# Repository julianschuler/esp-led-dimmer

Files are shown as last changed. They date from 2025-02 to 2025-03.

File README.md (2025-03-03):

# ESP LED Dimmer

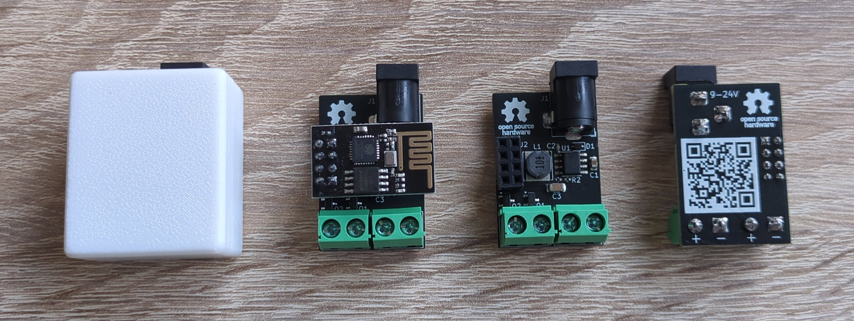
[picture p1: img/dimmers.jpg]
Four dimmers

*Four dimmers shown in different configurations from left to right: Fully assembled within a case, fully assembled, without the ESP-01 module and from the back.*

## Overview

This repository contains the PCB files for a wireless dimmer for up to two monochromatic LED strips based on the ESP-01. It can e.g. be integrated into [Home Assistant](https://www.home-assistant.io/) using [ESPHome](https://esphome.io/).

The dimmer is powered via a DC barrel jack and supports both 12V and 24V LED strips. The LED strips are connected via screw terminals.

It is designed to make use of the PCBA services of JLCPCB and uses as many basic parts as possible. You can use the awesome [KiCAD JLCPCB tools](https://github.com/Bouni/kicad-jlcpcb-tools) for exporting the corresponding fabrication files.
Excluding the ESP-01 module, the cost per assembled PCB is around 5€.

> **Warning:** Only power up the dimmer when the ESP-01 module is plugged in, otherwise it might get broken! This seems to be due to the power supply IC requiring a certain minimum current to be drawn.

## Using the dimmer with Home Assistant

To use the dimmer with Home Assistant, create a new ESP8266 device in the [ESPHome Device Builder](https://esphome.io/guides/getting_started_hassio.html) and append the following lines to its YAML file:

```yaml
output:
  - id: led1
    pin: GPIO2
    platform: esp8266_pwm
    frequency: 1000 Hz
  - id: led2
    pin: GPIO0
    platform: esp8266_pwm
    frequency: 1000 Hz

light:
  - output: led1
    name: "LED 1"
    platform: monochromatic
  - output: led2
    name: "LED 2"
    platform: monochromatic
```

Install the resulting configuration to the ESP-01 and insert it into the corresponding header on the dimmer.
Within a minute the dimmer should be available within Home Assistant.

## License

This project is licensed under the MIT license, see [`LICENSE.txt`](LICENSE.txt) for further information.

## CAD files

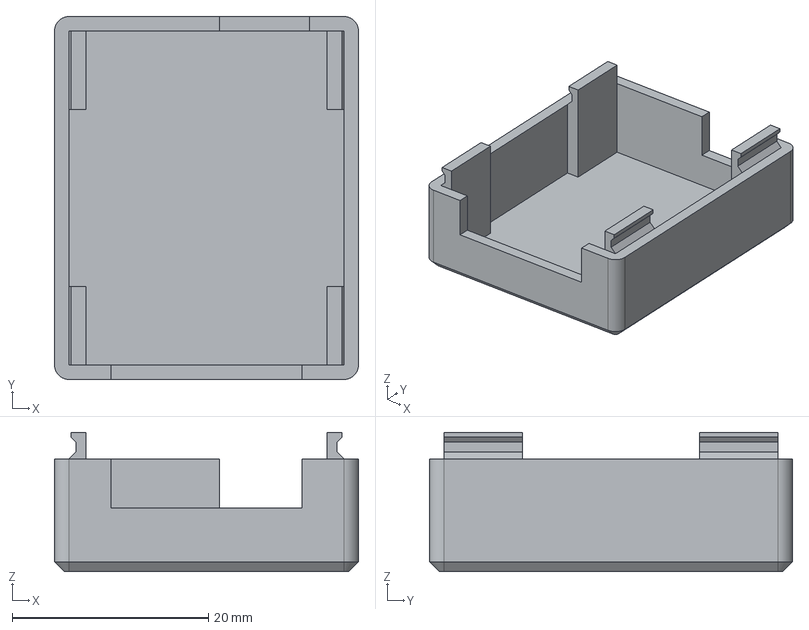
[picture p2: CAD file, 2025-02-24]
case/case-bottom.step
31.0 x 37.0 x 14.2 mm

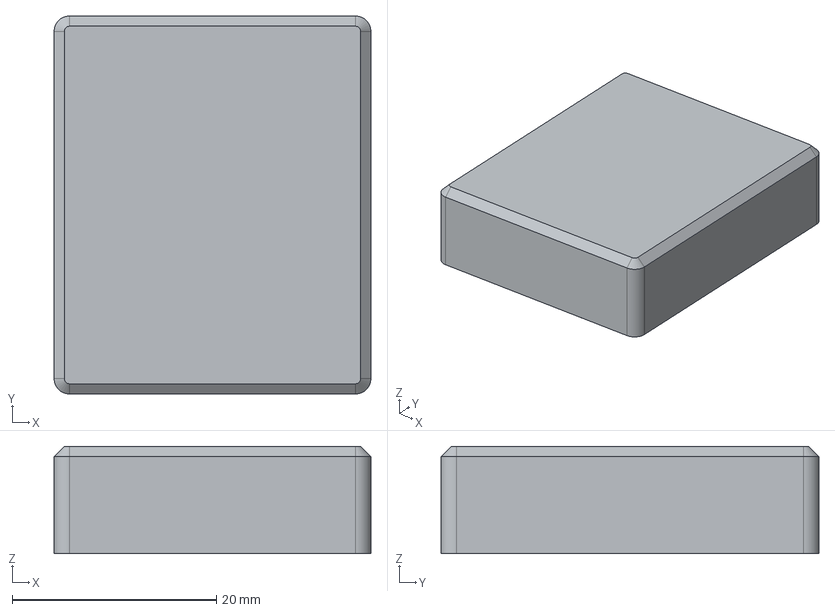
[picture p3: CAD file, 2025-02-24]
case/case-top.step
31.0 x 37.0 x 10.5 mm

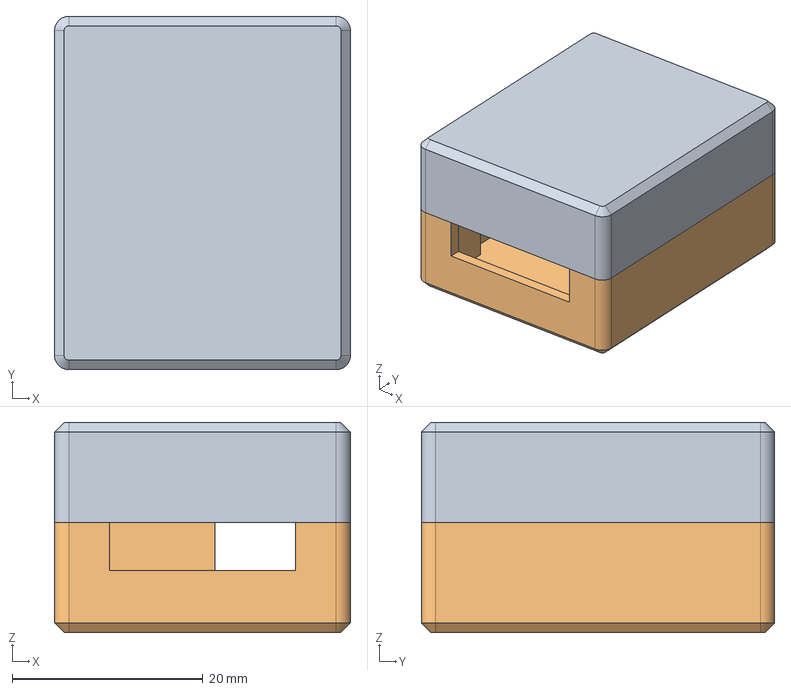
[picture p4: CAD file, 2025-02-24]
case/case.FCStd
31.0 x 37.0 x 22.0 mm
top
bottom

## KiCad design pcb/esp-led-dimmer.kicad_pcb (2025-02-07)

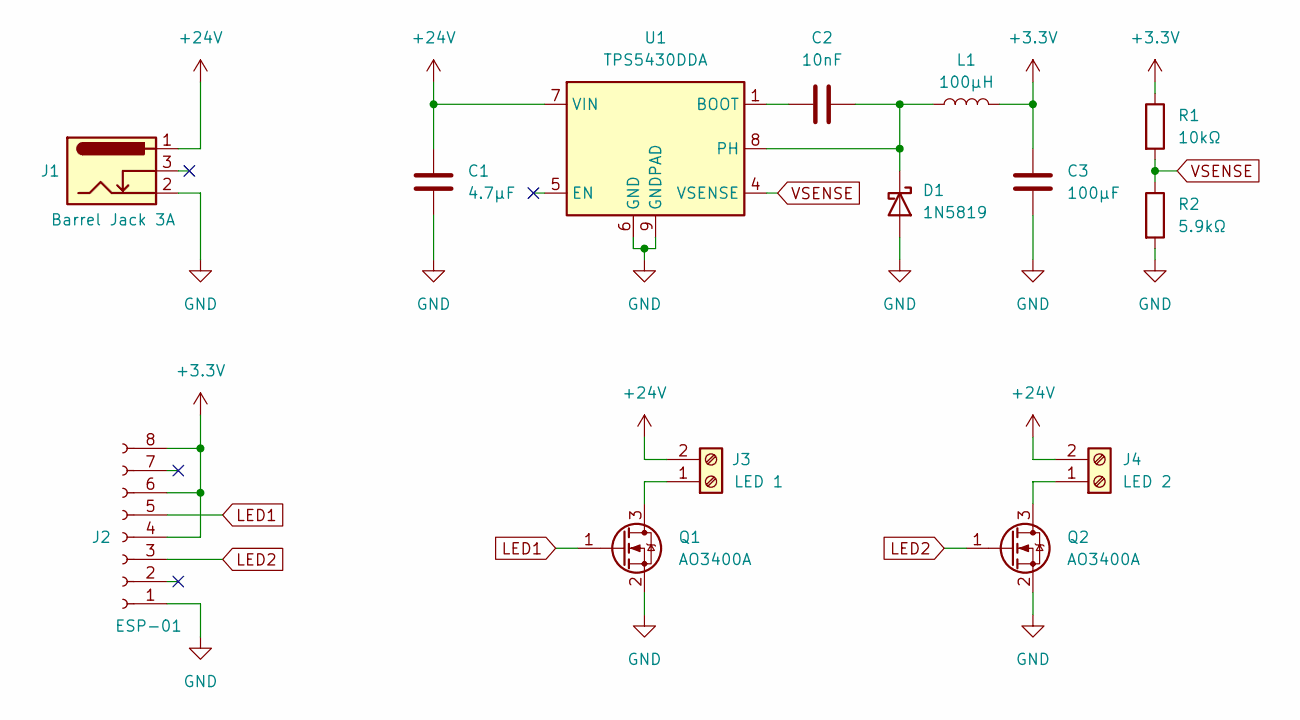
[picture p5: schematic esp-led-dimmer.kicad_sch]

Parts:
C1: 4.7µF; C_0805_2012Metric
C2: 10nF; C_0402_1005Metric
C3: 100µF; C_1206_3216Metric
D1: 1N5819; D_SOD-323
J1: Barrel Jack 3A; BarrelJack_Horizontal
J2: ESP-01; PinSocket_2x04_P2.54mm_Vertical
J3: LED 1; TerminalBlock_Phoenix_MKDS-1,5-2_1x02_P5.00mm_Horizontal
J4: LED 2; TerminalBlock_Phoenix_MKDS-1,5-2_1x02_P5.00mm_Horizontal
L1: 100µH; L_Bourns_SRN6045TA
Q1, Q2: AO3400A; SOT-23
R1: 10kΩ; R_0402_1005Metric
R2: 5.9kΩ; R_0402_1005Metric
U1: TPS5430DDA; TI_SO-PowerPAD-8_ThermalVias

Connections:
+3.3V: C3.2, J2.4, J2.6, J2.8, L1.1, R1.1
+24V: C1.2, J1.1, J3.2, J4.2, U1.7 (VIN)
GND: C1.1, C3.1, D1.2 (A), J1.2, J2.1, Q1.2 (S), Q2.2 (S), R2.2, U1.6 (GND), U1.9 (GNDPAD)
LED1: J2.5, Q1.1 (G)
LED2: J2.3, Q2.1 (G)
unnamed: C2.2, D1.1 (K), L1.2, U1.8 (PH)
unnamed: J3.1, Q1.3 (D)
unnamed: J4.1, Q2.3 (D)
unnamed: C2.1, U1.1 (BOOT)
VSENSE: R1.2, R2.1, U1.4 (VSENSE)

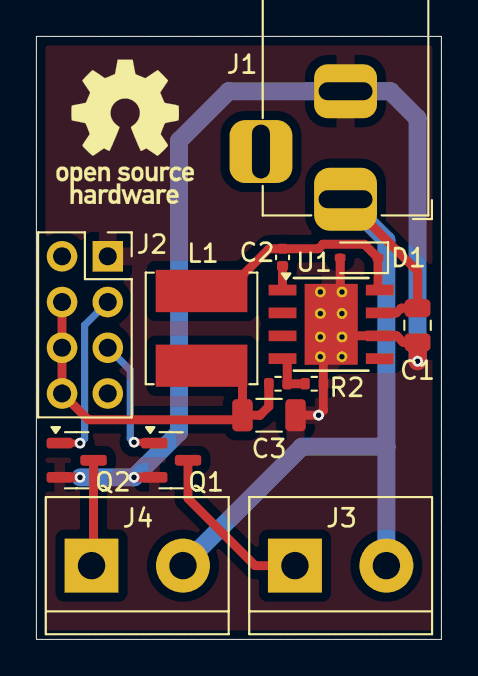
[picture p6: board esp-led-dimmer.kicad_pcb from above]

Board: 2 copper layers, 22.5 x 33.5 mm, 14 parts (0 on the bottom side), 10 nets.

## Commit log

2025-02-04 Add basic power supply circuit
    [esp-led-dimmer.kicad_sch]
2025-02-04 Add LED dimming circuit
    [esp-led-dimmer.kicad_sch]
2025-02-04 Replace LM2564 with TPS5430 for 3.3V power supply
    [esp-led-dimmer.kicad_sch]
2025-02-06 Assign footprints to schematic symbols
    [esp-led-dimmer.kicad_sch]
2025-02-06 Add PCB design
    [esp-led-dimmer.kicad_pcb]
2025-02-07 Add JLCPCB component IDs for PCBA
    [esp-led-dimmer.kicad_pcb]
2025-02-07 Adjust pin placement for barrel jack
    [esp-led-dimmer.kicad_pcb]
2025-02-07 Remove JLCPCB order marker placeholder
    [esp-led-dimmer.kicad_pcb]
2025-02-07 Replace screw terminal footprints
    [esp-led-dimmer.kicad_pcb]
2025-02-18 Move pcb files to subfolder
    [esp-led-dimmer.kicad_pcb, esp-led-dimmer.kicad_sch]
2025-02-24 Add case
    [case-bottom.step, case-top.step, case.FCStd]
